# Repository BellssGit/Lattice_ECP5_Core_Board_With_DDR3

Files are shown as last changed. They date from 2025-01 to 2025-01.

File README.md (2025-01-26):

# Lattice_ECP5_Core_Board_With_DDR3
A 6 layer Board, Using Lattice LFE5U-25F-BGA256 FPGA with 32bit wide DDR3 memory.

board

Connectivity:
  
  1. 8 Channel LVDS working up to 800Mbps per channel
  2. 24bit RGB display or general IO
  3. FT232H with FT245 FIFO support

On Board memory:
  
  1. 128Mbit Flash
  2. 2x2Gbit 16x2bit wide DDR3 memory

A [blog post](https://www.emoe.xyz/lattice_ecp5_board/) about this board (Chinese Only)

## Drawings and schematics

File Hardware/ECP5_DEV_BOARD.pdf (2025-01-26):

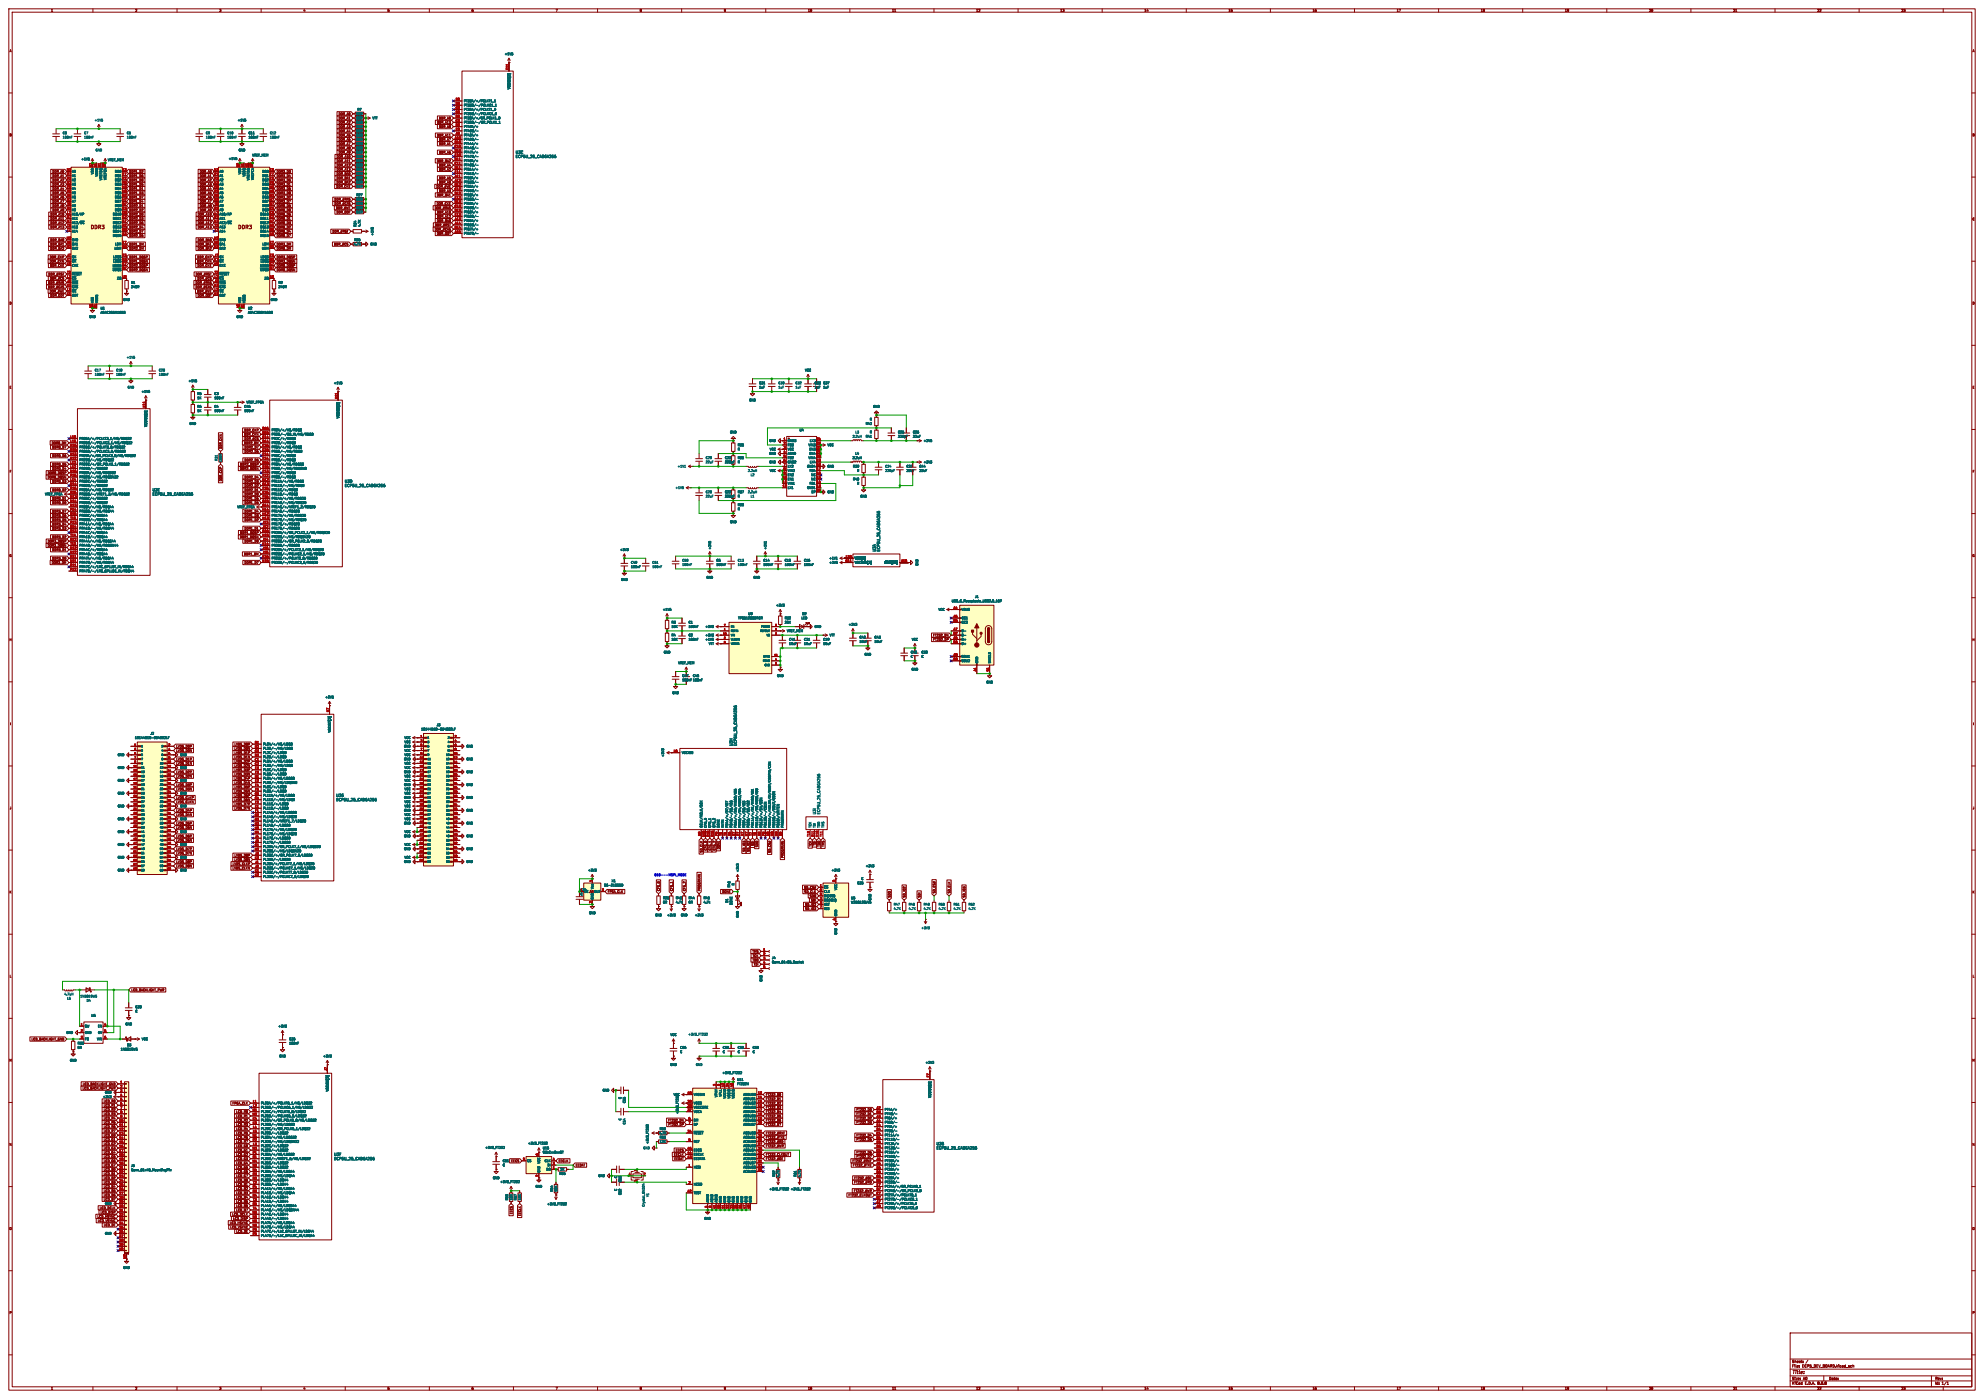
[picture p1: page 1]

DDR_A12 DDR_A11 DDR_A13 DDR_A10 DDR_A9 DDR_A8 DDR_#RST DDR_#RAS DDR_#CAS DDR_#CS DDR_#WE DDR_ODT DDR_BA2 DDR_BA1 DDR_BA0 DDR_CKP DDR_CKE DDR_CKN

GND GND GND GND GND GND GND GND GND

VCC GND GND GND
VCC

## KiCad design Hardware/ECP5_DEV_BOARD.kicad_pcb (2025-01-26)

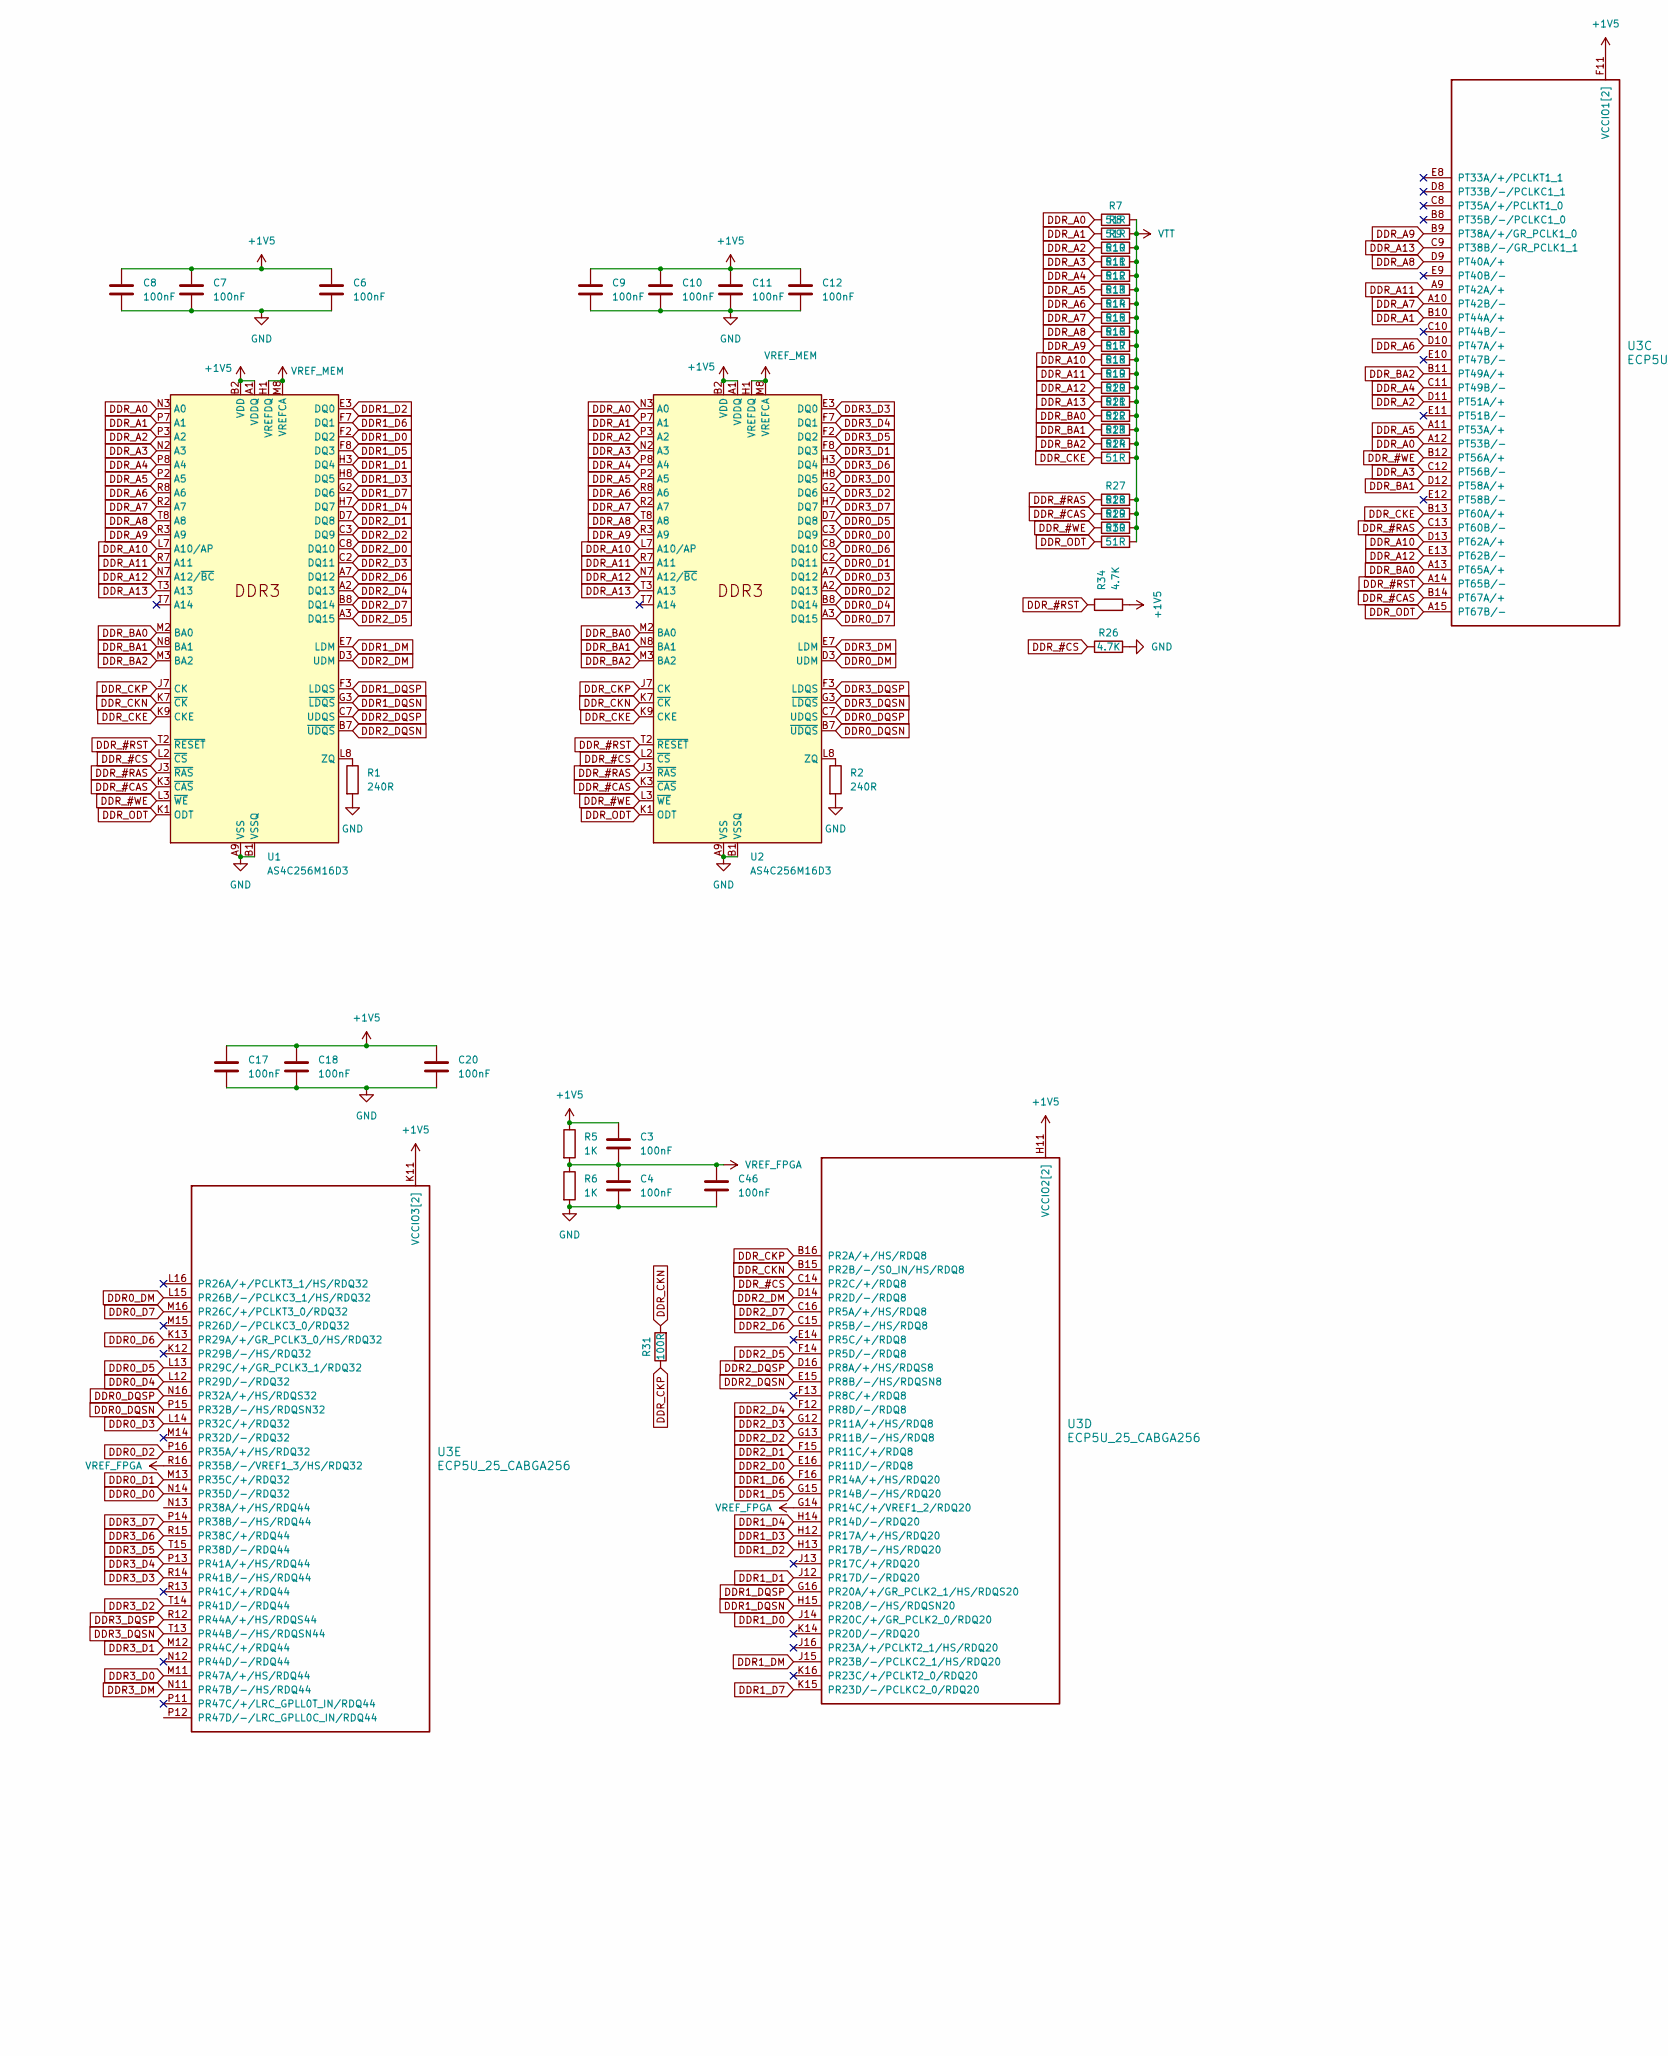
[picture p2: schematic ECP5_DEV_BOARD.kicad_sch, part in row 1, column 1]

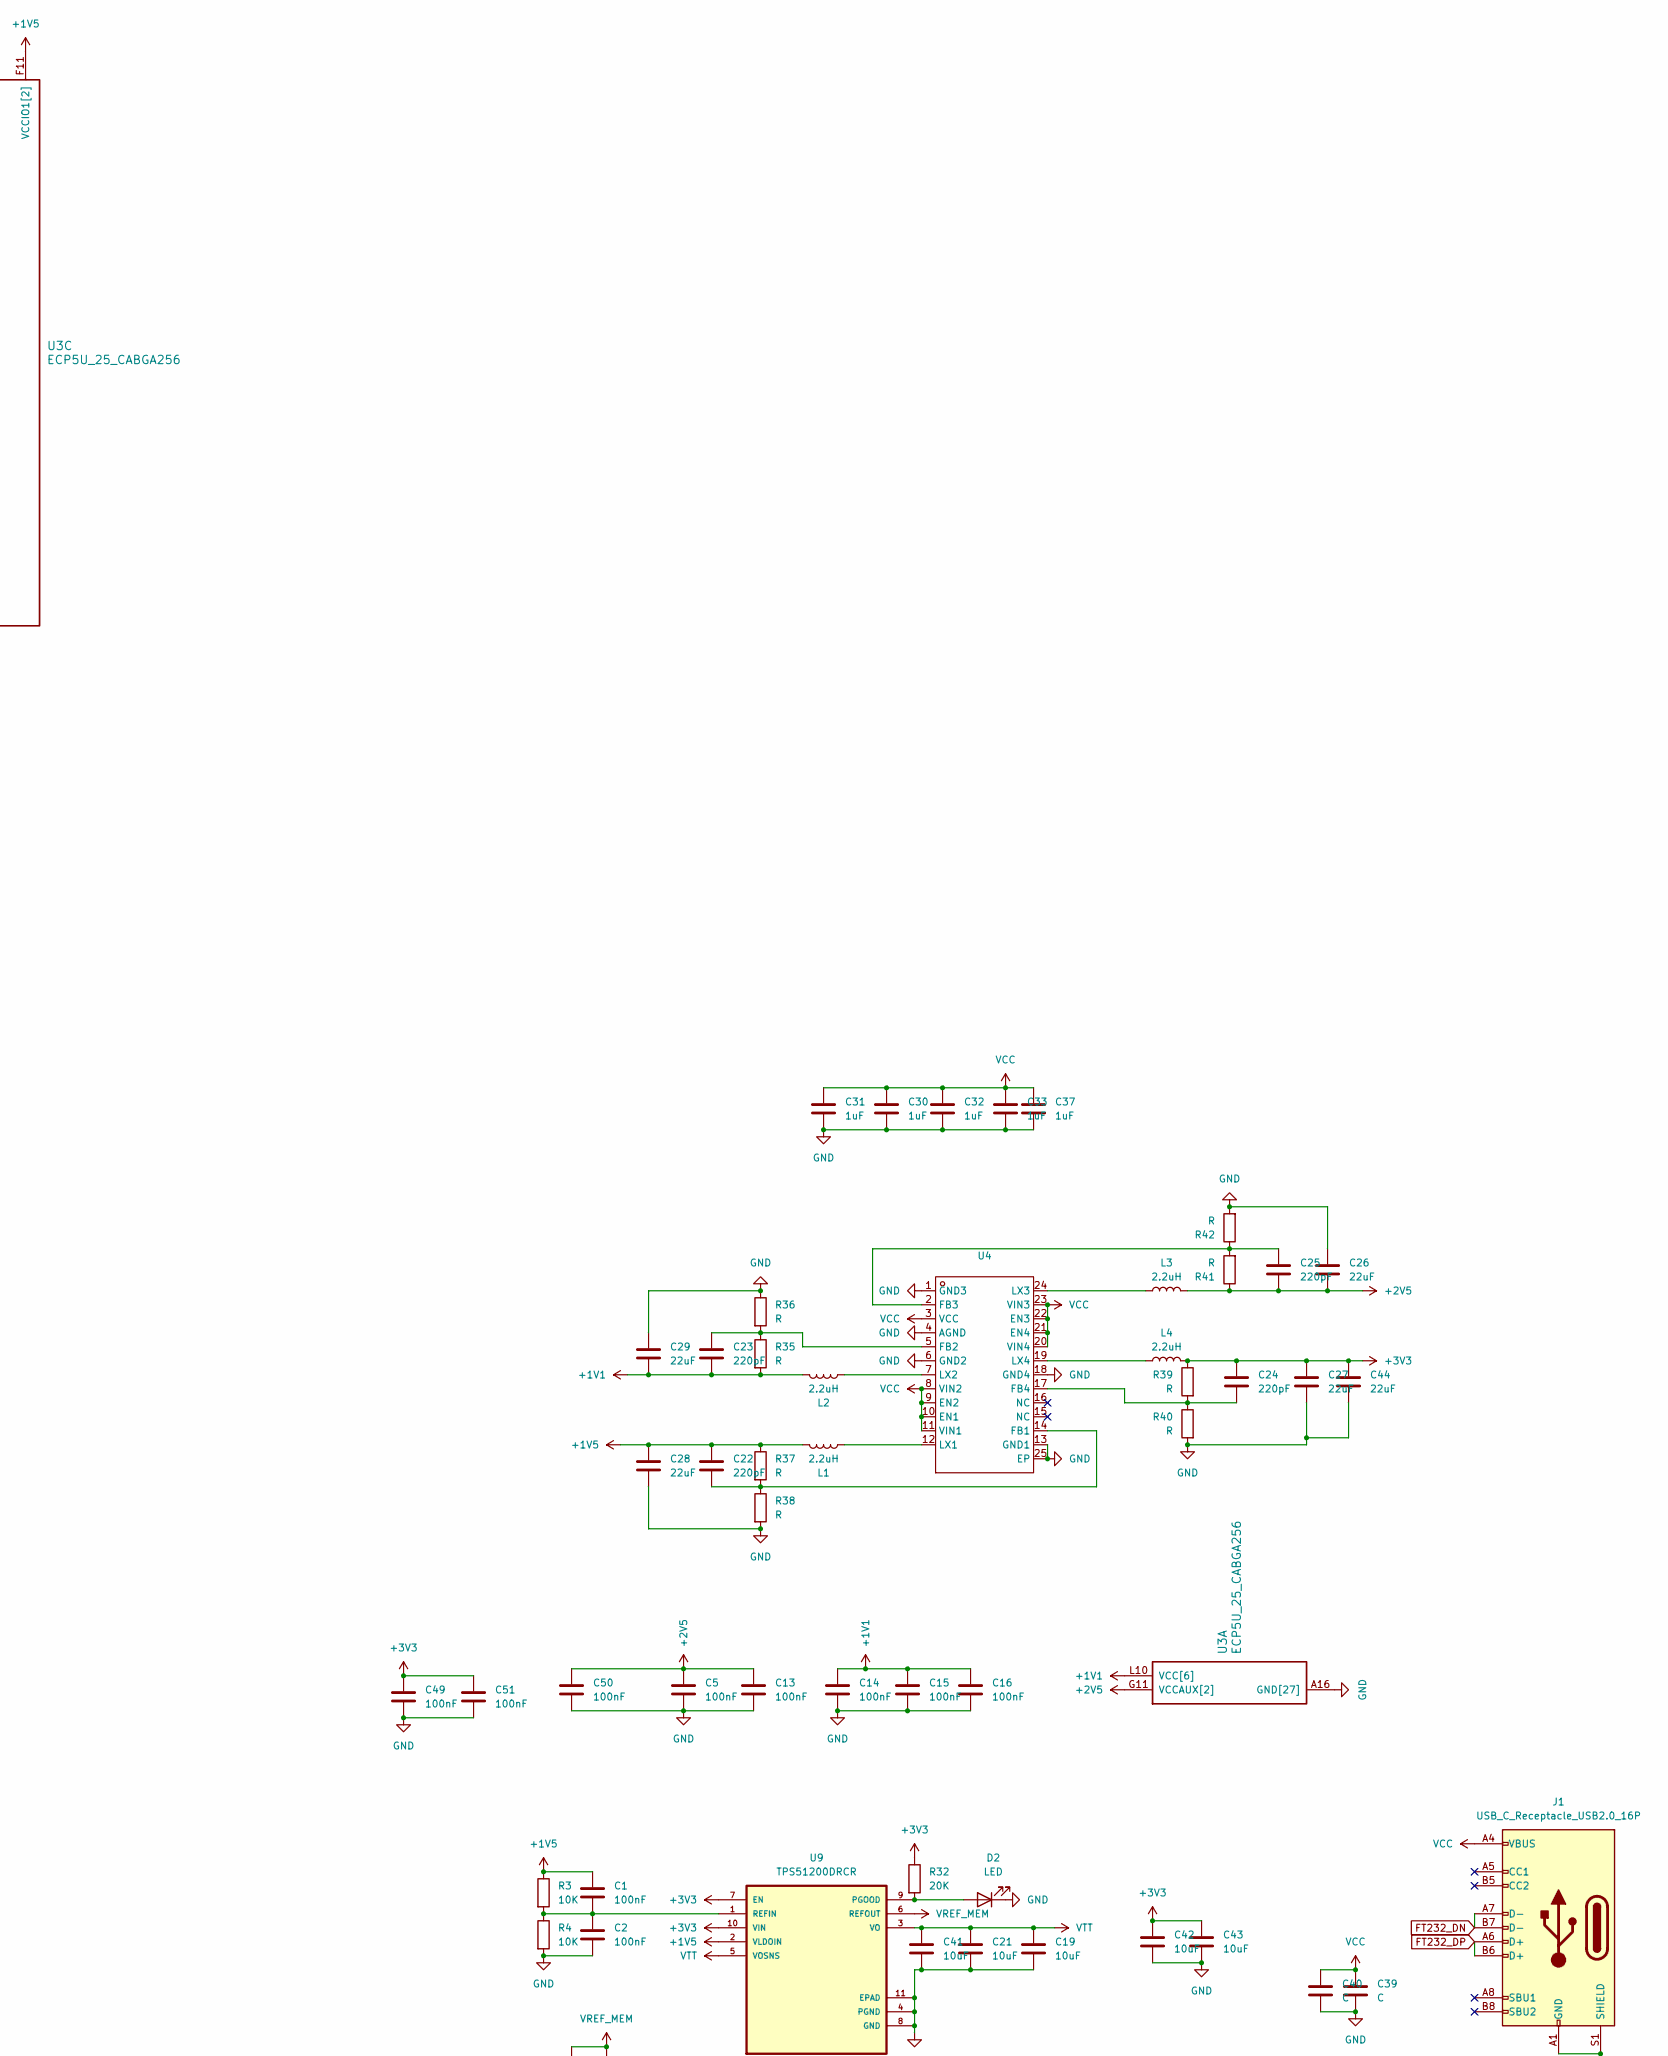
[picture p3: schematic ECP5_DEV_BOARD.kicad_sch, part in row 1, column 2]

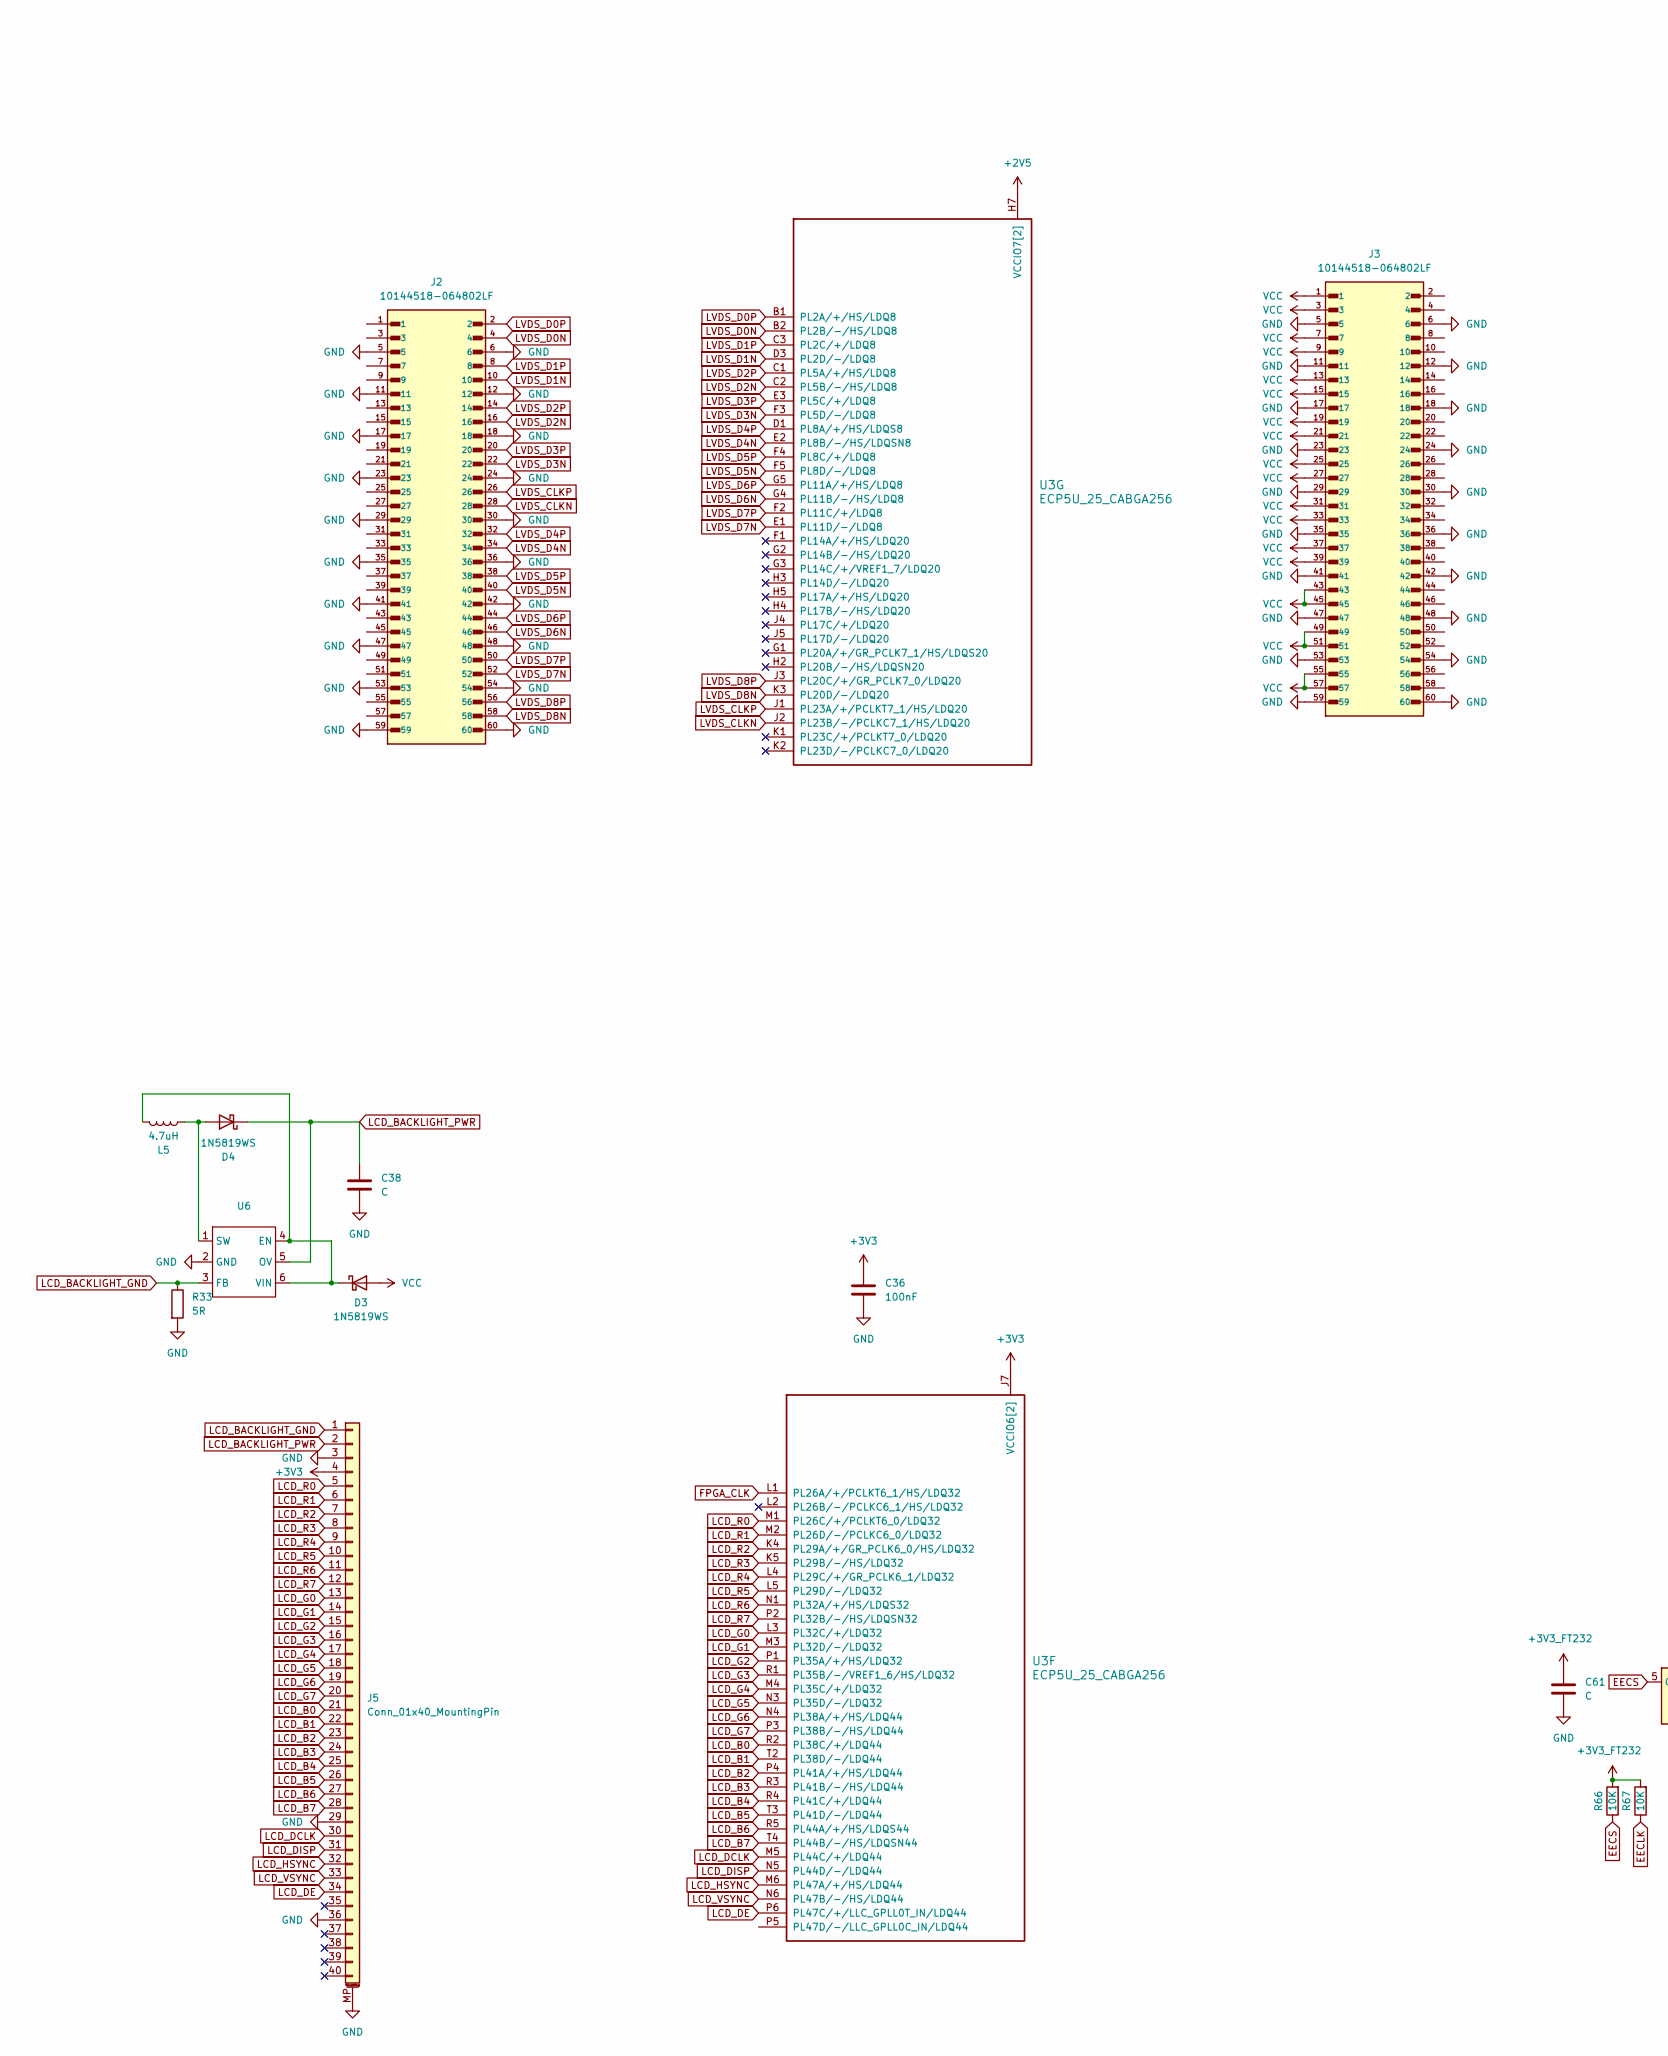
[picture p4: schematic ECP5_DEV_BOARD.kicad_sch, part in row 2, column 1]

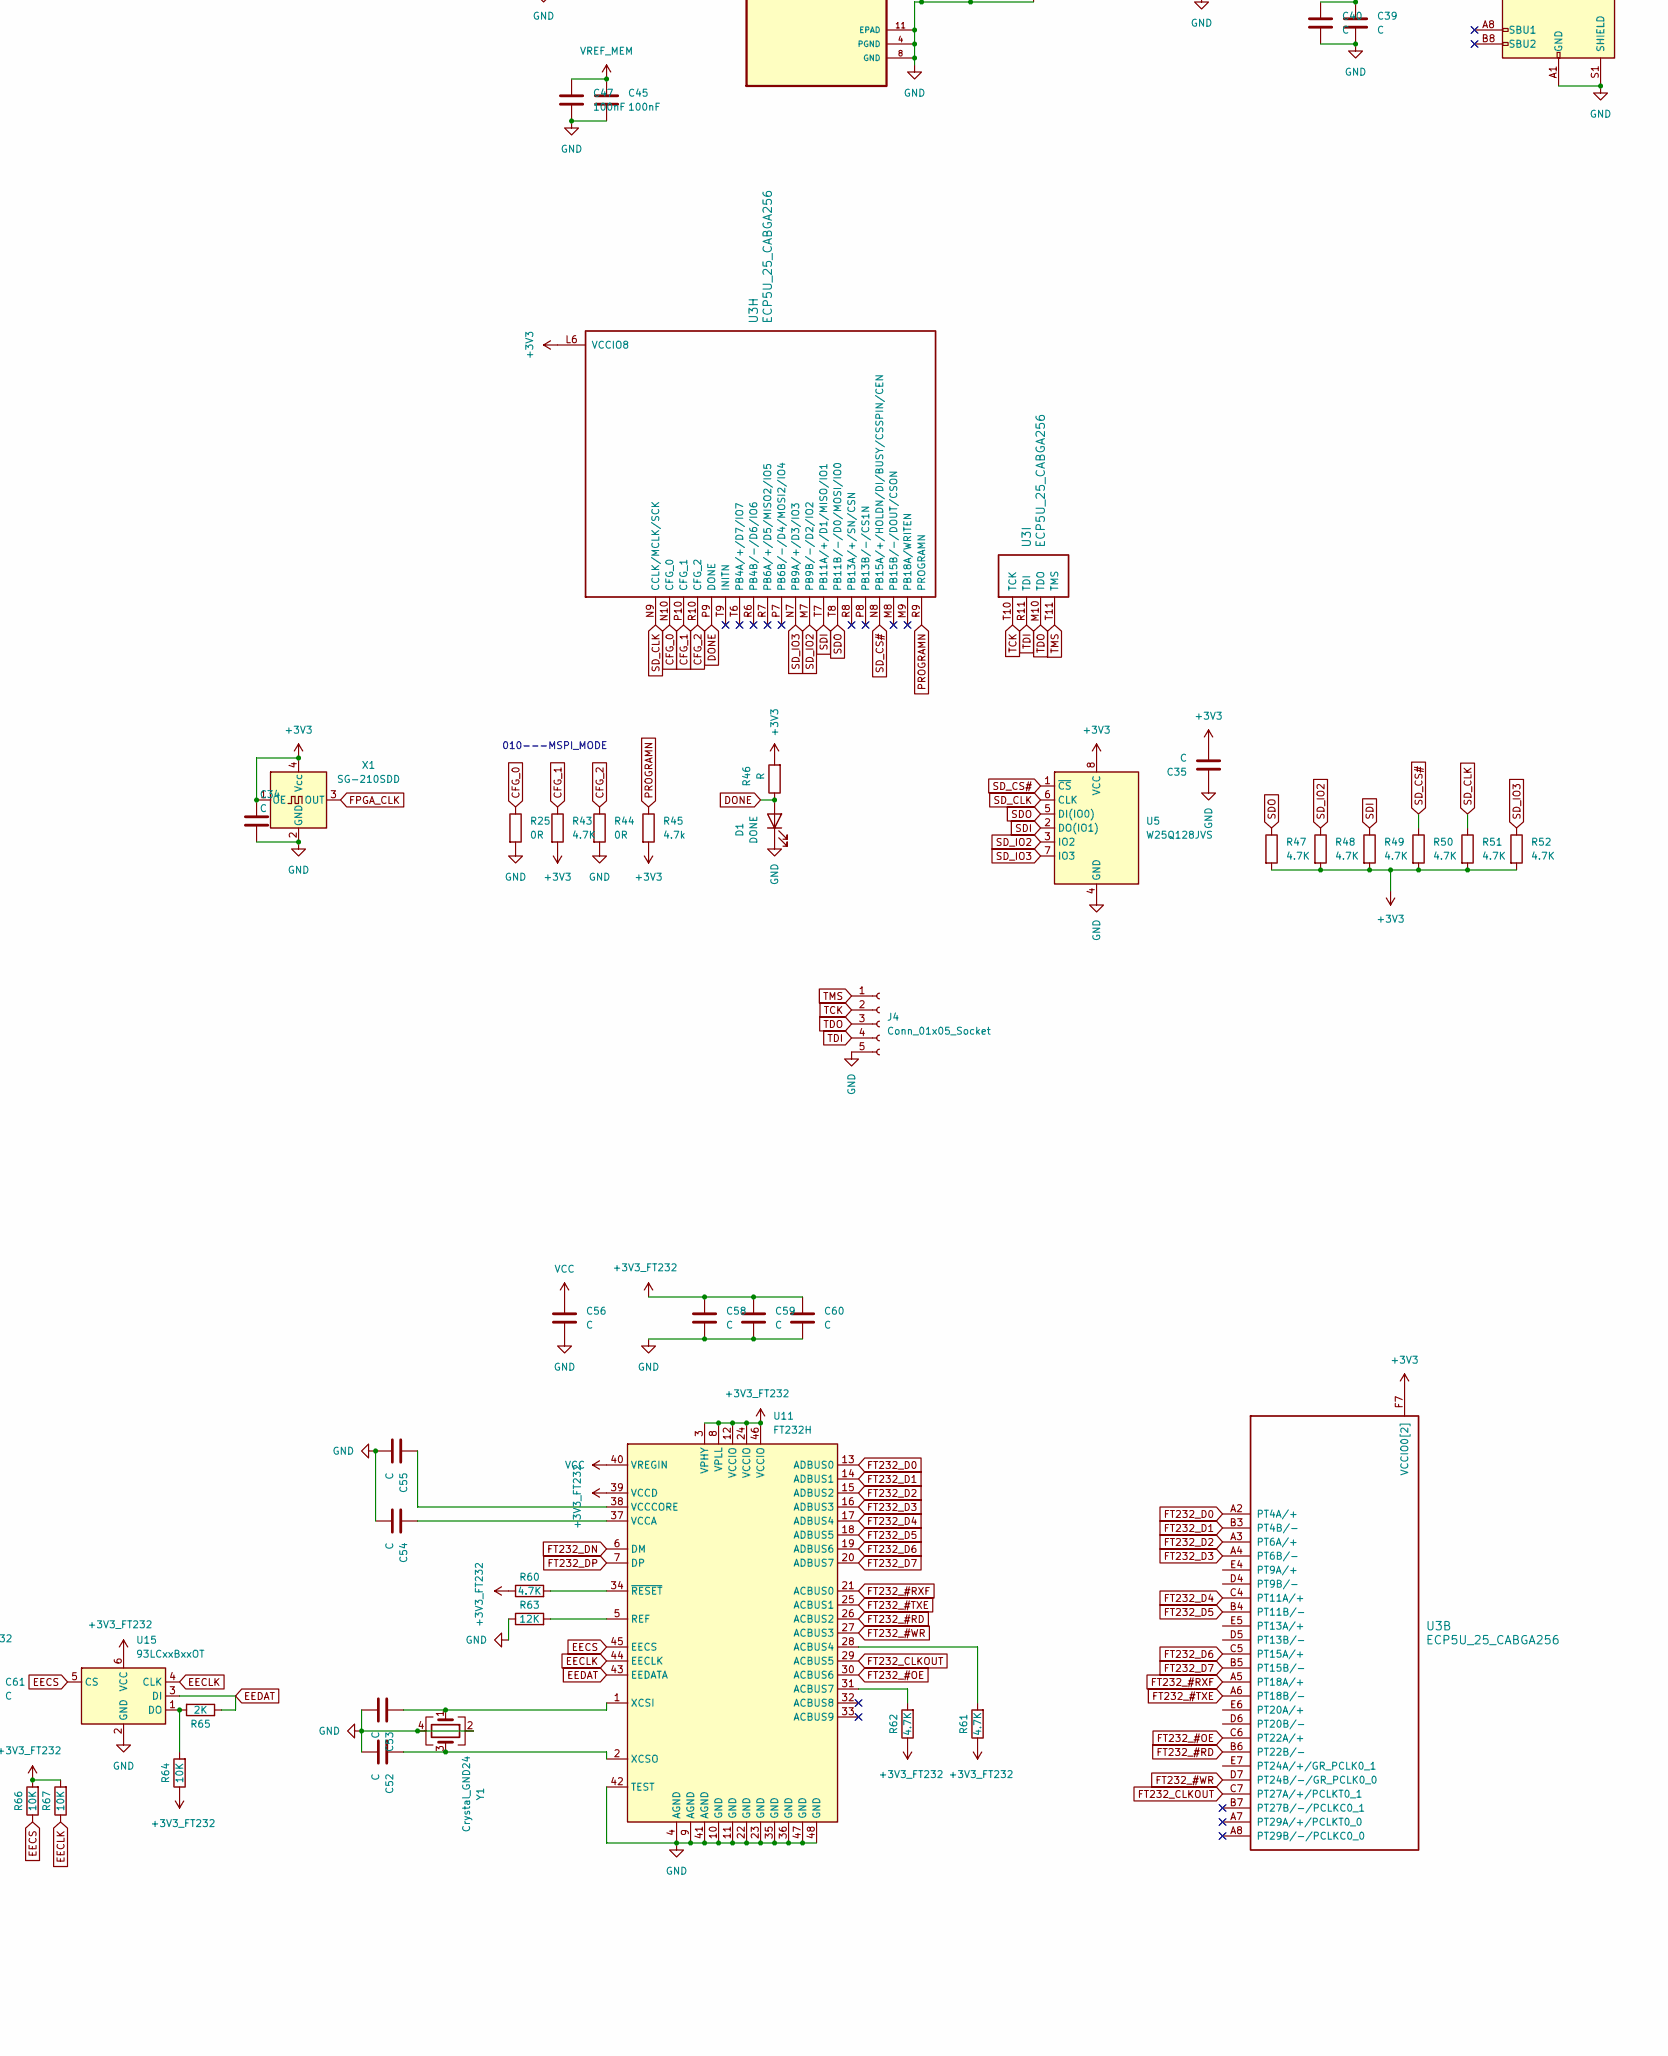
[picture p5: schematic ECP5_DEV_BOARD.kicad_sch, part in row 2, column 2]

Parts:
C1, C2, C3, C4, C47: 100nF; C_0603_1608Metric
C5, C6, C7, C8, C9, C10, C11, C12, C13, C14, C15, C16, C17, C18, C20, C36, C45, C46, C49, C50, C51: 100nF; C_0402_1005Metric
C19, C21, C41, C42, C43: 10uF; C_0603_1608Metric
C22, C23, C24, C25: 220pF; C_0603_1608Metric
C26, C27, C28, C29, C44: 22uF; C_0805_2012Metric
C30, C31, C32, C33, C37: 1uF; C_0603_1608Metric
C34, C35, C52, C53, C54, C55, C56, C58, C59, C60, C61: C; C_0603_1608Metric
C38, C39, C40: C; C_0805_2012Metric
D1: DONE; LED_0603_1608Metric_Pad1.05x0.95mm_HandSolder
D2: LED; LED_0603_1608Metric
D3, D4: 1N5819WS; D_SOD-323
J1: USB_C_Receptacle_USB2.0_16P; USB_C_Receptacle_G-Switch_GT-USB-7010ASV
J2, J3: 10144518-064802LF; AMPHENOL_10144518-064802LF; PARTREV H
J4: Conn_01x05_Socket; PinSocket_1x05_P2.54mm_Vertical
J5: Conn_01x40_MountingPin; TE_4-1734839-0_1x40-1MP_P0.5mm_Horizontal
L1, L2, L3, L4: 2.2uH; L_Changjiang_FNR252010S
L5: 4.7uH; L_Changjiang_FNR252010S
R1, R2: 240R; R_0402_1005Metric
R3, R4, R64, R66, R67: 10K; R_0603_1608Metric
R5, R6: 1K; R_0603_1608Metric
R7, R8, R9, R10, R11, R12, R13, R14, R15, R16, R17, R18, R19, R20, R21, R22, R23, R24, R27, R28, R29, R30: 51R; R_0402_1005Metric
R25, R44: 0R; R_0402_1005Metric
R26, R34, R43: 4.7K; R_0402_1005Metric
R31: 100R; R_0402_1005Metric
R32: 20K; R_0603_1608Metric
R33: 5R; R_0603_1608Metric
R35, R36, R37, R38, R39, R40, R41, R42: R; R_0603_1608Metric
R45: 4.7k; R_0402_1005Metric
R46: R; R_0603_1608Metric_Pad0.98x0.95mm_HandSolder
R47, R48, R49, R50, R51, R52: 4.7K; R_0603_1608Metric_Pad0.98x0.95mm_HandSolder
R60, R61, R62: 4.7K; R_0603_1608Metric
R63: 12K; R_0603_1608Metric
R65: 2K; R_0603_1608Metric
U1, U2: AS4C256M16D3; BGA-96_9.0x13.0mm_Layout2x3x16_P0.8mm
U3: ECP5U_25_CABGA256; BGA-256_14.0x14.0mm_Layout16x16_P0.8mm_Ball0.45mm_Pad0.32mm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
U4: VQFN-24-1EP_4x4mm_P0.5mm_EP2.5x2.5mm
U5: W25Q128JVS; SOIC-8_5.23x5.23mm_P1.27mm
U6: SOT-23-6
U9: TPS51200DRCR; VREG_V62_16624-01YE
U11: FT232H; LQFP-48_7x7mm_P0.5mm
U15: 93LCxxBxxOT; SOT-23-6
X1: SG-210SDD; Oscillator_SMD_Abracon_ASE-4Pin_3.2x2.5mm
Y1: Crystal_GND24; Crystal_SMD_3225-4Pin_3.2x2.5mm

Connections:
+1V1: C14.1, C15.1, C16.1, C23.2, C29.2, L2.1, R35.2, U3.G6 (VCC[6]), U3.G7 (VCC[6]), U3.G9 (VCC[6]), U3.L8 (VCC[6]), U3.L9 (VCC[6]), U3.L10 (VCC[6])
+1V5: C1.1, C3.1, C6.1, C7.1, C8.1, C9.1, C10.1, C11.1, C12.1, C17.1, C18.1, C20.1, C22.1, C28.1, L1.1, R3.1, R5.1, R34.2, R37.1, U1.A1 (VDDQ), U1.A8 (VDDQ), U1.B2 (VDD), U1.C1 (VDDQ), U1.C9 (VDDQ), U1.D2 (VDDQ), U1.D9 (VDD), U1.E9 (VDDQ), U1.F1 (VDDQ), U1.G7 (VDD), U1.H2 (VDDQ), U1.H9 (VDDQ), U1.K2 (VDD), U1.K8 (VDD), U1.N1 (VDD), U1.N9 (VDD), U1.R1 (VDD), U1.R9 (VDD), U2.A1 (VDDQ), U2.A8 (VDDQ), U2.B2 (VDD), U2.C1 (VDDQ), U2.C9 (VDDQ), U2.D2 (VDDQ), U2.D9 (VDD), U2.E9 (VDDQ), U2.F1 (VDDQ), U2.G7 (VDD), U2.H2 (VDDQ), U2.H9 (VDDQ), U2.K2 (VDD), U2.K8 (VDD), U2.N1 (VDD), U2.N9 (VDD), U2.R1 (VDD), U2.R9 (VDD), U3.F10 (VCCIO1[2]), U3.F11 (VCCIO1[2]), U3.H11 (VCCIO2[2]), U3.J11 (VCCIO2[2]), U3.K11 (VCCIO3[2]), U3.L11 (VCCIO3[2]), U9.2 (VLDOIN)
+2V5: C5.1, C13.1, C25.1, C26.2, C50.1, L3.2, R41.1, U3.G11 (VCCAUX[2]), U3.H6 (VCCIO7[2]), U3.H7 (VCCIO7[2]), U3.L7 (VCCAUX[2])
+3V3: C24.1, C27.1, C34.1, C35.2, C36.1, C42.1, C43.1, C44.1, C49.1, C51.1, J5.4, L4.2, R32.1, R39.1, R43.2, R45.2, R46.2, R47.2, R48.2, R49.2, R50.2, R51.2, R52.2, U3.F6 (VCCIO0[2]), U3.F7 (VCCIO0[2]), U3.J6 (VCCIO6[2]), U3.J7 (VCCIO6[2]), U3.L6 (VCCIO8), U5.8 (VCC), U9.7 (EN), U9.10 (VIN), X1.1 (OE), X1.4 (Vcc)
+3V3_FT232: C58.1, C59.1, C60.1, C61.1, R60.1, R61.1, R62.1, R64.1, R66.2, R67.2, U11.3 (VPHY), U11.8 (VPLL), U11.12 (VCCIO), U11.24 (VCCIO), U11.39 (VCCD), U11.46 (VCCIO), U15.6 (VCC)
CFG_0: R25.1, U3.N10 (CFG_0)
CFG_1: R43.1, U3.P10 (CFG_1)
CFG_2: R44.1, U3.R10 (CFG_2)
DDR0_D0: U2.C3 (DQ9), U3.N14 (PR35D/-/RDQ32)
DDR0_D1: U2.C2 (DQ11), U3.M13 (PR35C/+/RDQ32)
DDR0_D2: U2.A2 (DQ13), U3.P16 (PR35A/+/HS/RDQ32)
DDR0_D3: U2.A7 (DQ12), U3.L14 (PR32C/+/RDQ32)
DDR0_D4: U2.B8 (DQ14), U3.L12 (PR29D/-/RDQ32)
DDR0_D5: U2.D7 (DQ8), U3.L13 (PR29C/+/GR_PCLK3_1/RDQ32)
DDR0_D6: U2.C8 (DQ10), U3.K13 (PR29A/+/GR_PCLK3_0/HS/RDQ32)
DDR0_D7: U2.A3 (DQ15), U3.M16 (PR26C/+/PCLKT3_0/RDQ32)
DDR0_DM: U2.D3 (UDM), U3.L15 (PR26B/-/PCLKC3_1/HS/RDQ32)
DDR0_DQSN: U2.B7 (~UDQS), U3.P15 (PR32B/-/HS/RDQSN32)
DDR0_DQSP: U2.C7 (UDQS), U3.N16 (PR32A/+/HS/RDQS32)
DDR1_D0: U1.F2 (DQ2), U3.J14 (PR20C/+/GR_PCLK2_0/RDQ20)
DDR1_D1: U1.H3 (DQ4), U3.J12 (PR17D/-/RDQ20)
DDR1_D2: U1.E3 (DQ0), U3.H13 (PR17B/-/HS/RDQ20)
DDR1_D3: U1.H8 (DQ5), U3.H12 (PR17A/+/HS/RDQ20)
DDR1_D4: U1.H7 (DQ7), U3.H14 (PR14D/-/RDQ20)
DDR1_D5: U1.F8 (DQ3), U3.G15 (PR14B/-/HS/RDQ20)
DDR1_D6: U1.F7 (DQ1), U3.F16 (PR14A/+/HS/RDQ20)
DDR1_D7: U1.G2 (DQ6), U3.K15 (PR23D/-/PCLKC2_0/RDQ20)
DDR1_DM: U1.E7 (LDM), U3.J15 (PR23B/-/PCLKC2_1/HS/RDQ20)
DDR1_DQSN: U1.G3 (~LDQS), U3.H15 (PR20B/-/HS/RDQSN20)
DDR1_DQSP: U1.F3 (LDQS), U3.G16 (PR20A/+/GR_PCLK2_1/HS/RDQS20)
DDR2_D0: U1.C8 (DQ10), U3.E16 (PR11D/-/RDQ8)
DDR2_D1: U1.D7 (DQ8), U3.F15 (PR11C/+/RDQ8)
DDR2_D2: U1.C3 (DQ9), U3.G13 (PR11B/-/HS/RDQ8)
DDR2_D3: U1.C2 (DQ11), U3.G12 (PR11A/+/HS/RDQ8)
DDR2_D4: U1.A2 (DQ13), U3.F12 (PR8D/-/RDQ8)
DDR2_D5: U1.A3 (DQ15), U3.F14 (PR5D/-/RDQ8)
DDR2_D6: U1.A7 (DQ12), U3.C15 (PR5B/-/HS/RDQ8)
DDR2_D7: U1.B8 (DQ14), U3.C16 (PR5A/+/HS/RDQ8)
DDR2_DM: U1.D3 (UDM), U3.D14 (PR2D/-/RDQ8)
DDR2_DQSN: U1.B7 (~UDQS), U3.E15 (PR8B/-/HS/RDQSN8)
DDR2_DQSP: U1.C7 (UDQS), U3.D16 (PR8A/+/HS/RDQS8)
DDR3_D0: U2.H8 (DQ5), U3.M11 (PR47A/+/HS/RDQ44)
DDR3_D1: U2.F8 (DQ3), U3.M12 (PR44C/+/RDQ44)
DDR3_D2: U2.G2 (DQ6), U3.T14 (PR41D/-/RDQ44)
DDR3_D3: U2.E3 (DQ0), U3.R14 (PR41B/-/HS/RDQ44)
DDR3_D4: U2.F7 (DQ1), U3.P13 (PR41A/+/HS/RDQ44)
DDR3_D5: U2.F2 (DQ2), U3.T15 (PR38D/-/RDQ44)
DDR3_D6: U2.H3 (DQ4), U3.R15 (PR38C/+/RDQ44)
DDR3_D7: U2.H7 (DQ7), U3.P14 (PR38B/-/HS/RDQ44)
DDR3_DM: U2.E7 (LDM), U3.N11 (PR47B/-/HS/RDQ44)
DDR3_DQSN: U2.G3 (~LDQS), U3.T13 (PR44B/-/HS/RDQSN44)
DDR3_DQSP: U2.F3 (LDQS), U3.R12 (PR44A/+/HS/RDQS44)
DDR_#CAS: R28.1, U1.K3 (~CAS), U2.K3 (~CAS), U3.B14 (PT67A/+)
DDR_#CS: R26.1, U1.L2 (~CS), U2.L2 (~CS), U3.C14 (PR2C/+/RDQ8)
DDR_#RAS: R27.1, U1.J3 (~RAS), U2.J3 (~RAS), U3.C13 (PT60B/-)
DDR_#RST: R34.1, U1.T2 (~RESET), U2.T2 (~RESET), U3.A14 (PT65B/-)
DDR_#WE: R29.1, U1.L3 (~WE), U2.L3 (~WE), U3.B12 (PT56A/+)
DDR_A0: R7.1, U1.N3 (A0), U2.N3 (A0), U3.A12 (PT53B/-)
DDR_A1: R8.1, U1.P7 (A1), U2.P7 (A1), U3.B10 (PT44A/+)
DDR_A2: R9.1, U1.P3 (A2), U2.P3 (A2), U3.D11 (PT51A/+)
DDR_A3: R10.1, U1.N2 (A3), U2.N2 (A3), U3.C12 (PT56B/-)
DDR_A4: R11.1, U1.P8 (A4), U2.P8 (A4), U3.C11 (PT49B/-)
DDR_A5: R12.1, U1.P2 (A5), U2.P2 (A5), U3.A11 (PT53A/+)
DDR_A6: R13.1, U1.R8 (A6), U2.R8 (A6), U3.D10 (PT47A/+)
DDR_A7: R14.1, U1.R2 (A7), U2.R2 (A7), U3.A10 (PT42B/-)
DDR_A8: R15.1, U1.T8 (A8), U2.T8 (A8), U3.D9 (PT40A/+)
DDR_A9: R16.1, U1.R3 (A9), U2.R3 (A9), U3.B9 (PT38A/+/GR_PCLK1_0)
DDR_A10: R17.1, U1.L7 (A10/AP), U2.L7 (A10/AP), U3.D13 (PT62A/+)
DDR_A11: R18.1, U1.R7 (A11), U2.R7 (A11), U3.A9 (PT42A/+)
DDR_A12: R19.1, U1.N7 (A12/~BC), U2.N7 (A12/~BC), U3.E13 (PT62B/-)
DDR_A13: R20.1, U1.T3 (A13), U2.T3 (A13), U3.C9 (PT38B/-/GR_PCLK1_1)
DDR_BA0: R21.1, U1.M2 (BA0), U2.M2 (BA0), U3.A13 (PT65A/+)
DDR_BA1: R22.1, U1.N8 (BA1), U2.N8 (BA1), U3.D12 (PT58A/+)
DDR_BA2: R23.1, U1.M3 (BA2), U2.M3 (BA2), U3.B11 (PT49A/+)
DDR_CKE: R24.1, U1.K9 (CKE), U2.K9 (CKE), U3.B13 (PT60A/+)
DDR_CKN: R31.2, U1.K7 (~CK), U2.K7 (~CK), U3.B15 (PR2B/-/S0_IN/HS/RDQ8)
DDR_CKP: R31.1, U1.J7 (CK), U2.J7 (CK), U3.B16 (PR2A/+/HS/RDQ8)
DDR_ODT: R30.1, U1.K1 (ODT), U2.K1 (ODT), U3.A15 (PT67B/-)
DONE: D1.2 (A), R46.1, U3.P9 (DONE)
EECLK: R67.1, U11.44 (EECLK), U15.4 (CLK)
EECS: R66.1, U11.45 (EECS), U15.5 (CS)
EEDAT: R65.1, U11.43 (EEDATA), U15.3 (DI)
FPGA_CLK: U3.L1 (PL26A/+/PCLKT6_1/HS/LDQ32), X1.3 (OUT)
FT232_#OE: U3.C6 (PT22A/+), U11.30 (ACBUS6)
FT232_#RD: U3.B6 (PT22B/-), U11.26 (ACBUS2)
FT232_#RXF: U3.A5 (PT18A/+), U11.21 (ACBUS0)
FT232_#TXE: U3.A6 (PT18B/-), U11.25 (ACBUS1)
FT232_#WR: U3.D7 (PT24B/-/GR_PCLK0_0), U11.27 (ACBUS3)
FT232_CLKOUT: U3.C7 (PT27A/+/PCLKT0_1), U11.29 (ACBUS5)
FT232_D0: U3.A2 (PT4A/+), U11.13 (ADBUS0)
FT232_D1: U3.B3 (PT4B/-), U11.14 (ADBUS1)
FT232_D2: U3.A3 (PT6A/+), U11.15 (ADBUS2)
FT232_D3: U3.A4 (PT6B/-), U11.16 (ADBUS3)
FT232_D4: U3.C4 (PT11A/+), U11.17 (ADBUS4)
FT232_D5: U3.B4 (PT11B/-), U11.18 (ADBUS5)
FT232_D6: U3.C5 (PT15A/+), U11.19 (ADBUS6)
FT232_D7: U3.B5 (PT15B/-), U11.20 (ADBUS7)
FT232_DN: J1.A7 (D-), J1.B7 (D-), U11.6 (DM)
FT232_DP: J1.A6 (D+), J1.B6 (D+), U11.7 (DP)
GND: C2.2, C4.2, C5.2, C6.2, C7.2, C8.2, C9.2, C10.2, C11.2, C12.2, C13.2, C14.2, C15.2, C16.2, C17.2, C18.2, C19.2, C20.2, C21.2, C26.1, C27.2, C28.2, C29.1, C30.1, C31.1, C32.1, C33.1, C34.2, C35.1, C36.2, C37.1, C38.2, C39.2, C40.2, C41.2, C42.2, C43.2, C44.2, C45.2, C46.2, C47.2, C49.2, C50.2, C51.2, C52.2, C53.2, C54.2, C55.2, C56.2, C58.2, C59.2, C60.2, C61.2, D1.1 (K), D2.1 (K), J1.A1 (GND), J1.A12 (GND), J1.B1 (GND), J1.B12 (GND), J1.S1 (SHIELD), J2.5, J2.6, J2.11, J2.12, J2.17, J2.18, J2.23, J2.24, J2.29, J2.30, J2.35, J2.36, J2.41, J2.42, J2.47, J2.48, J2.53, J2.54, J2.59, J2.60, J3.5, J3.6, J3.11, J3.12, J3.17, J3.18, J3.23, J3.24, J3.29, J3.30, J3.35, J3.36, J3.41, J3.42, J3.47, J3.48, J3.53, J3.54, J3.59, J3.60, J4.5, J5.3, J5.29, J5.36, J5.MP (MountPin), R1.2, R2.2, R4.2, R6.2, R25.2, R26.2, R33.2, R36.1, R38.2, R40.2, R42.2, R44.2, R63.1, U1.A9 (VSS), U1.B1 (VSSQ), U1.B3 (VSS), U1.B9 (VSSQ), U1.D1 (VSSQ), U1.D8 (VSSQ), U1.E1 (VSS), U1.E2 (VSSQ), U1.E8 (VSSQ), U1.F9 (VSSQ), U1.G1 (VSSQ), U1.G8 (VSS), U1.G9 (VSSQ), U1.J2 (VSS), U1.J8 (VSS), U1.M1 (VSS), U1.M9 (VSS), U1.P1 (VSS), U1.P9 (VSS), U1.T1 (VSS), U1.T9 (VSS), U2.A9 (VSS), U2.B1 (VSSQ), U2.B3 (VSS), U2.B9 (VSSQ), U2.D1 (VSSQ), U2.D8 (VSSQ), U2.E1 (VSS), U2.E2 (VSSQ), U2.E8 (VSSQ), U2.F9 (VSSQ), U2.G1 (VSSQ), U2.G8 (VSS), U2.G9 (VSSQ), U2.J2 (VSS), U2.J8 (VSS), U2.M1 (VSS), U2.M9 (VSS), U2.P1 (VSS), U2.P9 (VSS), U2.T1 (VSS), U2.T9 (VSS), U3.A1 (GND[27]), U3.A16 (GND[27]), U3.D2 (GND[27]), U3.D15 (GND[27]), U3.F8 (GND[27]), U3.F9 (GND[27]), U3.G8 (GND[27]), U3.G10 (GND[27]), U3.H1 (GND[27]), U3.H8 (GND[27]), U3.H9 (GND[27]), U3.H10 (GND[27]), U3.H16 (GND[27]), U3.J8 (GND[27]), U3.J9 (GND[27]), U3.J10 (GND[27]), U3.K6 (GND[27]), U3.K7 (GND[27]), U3.K8 (GND[27]), U3.K9 (GND[27]), U3.K10 (GND[27]), U3.N2 (GND[27]), U3.N15 (GND[27]), U3.T1 (GND[27]), U3.T5 (GND[27]), U3.T12 (GND[27]), U3.T16 (GND[27]), U4.1 (GND3), U4.4 (AGND), U4.6 (GND2), U4.13 (GND1), U4.18 (GND4), U4.25 (EP), U5.4 (GND), U6.2 (GND), U9.4 (PGND), U9.8 (GND), U9.11 (EPAD), U11.4 (AGND), U11.9 (AGND), U11.10 (GND), U11.11 (GND), U11.22 (GND), U11.23 (GND), U11.35 (GND), U11.36 (GND), U11.41 (AGND), U11.42 (TEST), U11.47 (GND), U11.48 (GND), U15.2 (GND), X1.2 (GND), Y1.2, Y1.4
LCD_B0: J5.21, U3.R2 (PL38C/+/LDQ44)
LCD_B1: J5.22, U3.T2 (PL38D/-/LDQ44)
LCD_B2: J5.23, U3.P4 (PL41A/+/HS/LDQ44)
LCD_B3: J5.24, U3.R3 (PL41B/-/HS/LDQ44)
LCD_B4: J5.25, U3.R4 (PL41C/+/LDQ44)
LCD_B5: J5.26, U3.T3 (PL41D/-/LDQ44)
LCD_B6: J5.27, U3.R5 (PL44A/+/HS/LDQS44)
LCD_B7: J5.28, U3.T4 (PL44B/-/HS/LDQSN44)
LCD_BACKLIGHT_GND: J5.1, R33.1, U6.3 (FB)
LCD_BACKLIGHT_PWR: C38.1, D4.1 (K), J5.2, U6.5 (OV)
LCD_DCLK: J5.30, U3.M5 (PL44C/+/LDQ44)
LCD_DE: J5.34, U3.P6 (PL47C/+/LLC_GPLL0T_IN/LDQ44)
LCD_DISP: J5.31, U3.N5 (PL44D/-/LDQ44)
LCD_G0: J5.13, U3.L3 (PL32C/+/LDQ32)
LCD_G1: J5.14, U3.M3 (PL32D/-/LDQ32)
LCD_G2: J5.15, U3.P1 (PL35A/+/HS/LDQ32)
LCD_G3: J5.16, U3.R1 (PL35B/-/VREF1_6/HS/LDQ32)
LCD_G4: J5.17, U3.M4 (PL35C/+/LDQ32)
LCD_G5: J5.18, U3.N3 (PL35D/-/LDQ32)
LCD_G6: J5.19, U3.N4 (PL38A/+/HS/LDQ44)
LCD_G7: J5.20, U3.P3 (PL38B/-/HS/LDQ44)
LCD_HSYNC: J5.32, U3.M6 (PL47A/+/HS/LDQ44)
LCD_R0: J5.5, U3.M1 (PL26C/+/PCLKT6_0/LDQ32)
LCD_R1: J5.6, U3.M2 (PL26D/-/PCLKC6_0/LDQ32)
LCD_R2: J5.7, U3.K4 (PL29A/+/GR_PCLK6_0/HS/LDQ32)
LCD_R3: J5.8, U3.K5 (PL29B/-/HS/LDQ32)
LCD_R4: J5.9, U3.L4 (PL29C/+/GR_PCLK6_1/LDQ32)
LCD_R5: J5.10, U3.L5 (PL29D/-/LDQ32)
LCD_R6: J5.11, U3.N1 (PL32A/+/HS/LDQS32)
LCD_R7: J5.12, U3.P2 (PL32B/-/HS/LDQSN32)
LCD_VSYNC: J5.33, U3.N6 (PL47B/-/HS/LDQ44)
LVDS_CLKN: J2.28, U3.J2 (PL23B/-/PCLKC7_1/HS/LDQ20)
LVDS_CLKP: J2.26, U3.J1 (PL23A/+/PCLKT7_1/HS/LDQ20)
LVDS_D0N: J2.4, U3.B2 (PL2B/-/HS/LDQ8)
LVDS_D0P: J2.2, U3.B1 (PL2A/+/HS/LDQ8)
LVDS_D1N: J2.10, U3.D3 (PL2D/-/LDQ8)
LVDS_D1P: J2.8, U3.C3 (PL2C/+/LDQ8)
LVDS_D2N: J2.16, U3.C2 (PL5B/-/HS/LDQ8)
LVDS_D2P: J2.14, U3.C1 (PL5A/+/HS/LDQ8)
LVDS_D3N: J2.22, U3.F3 (PL5D/-/LDQ8)
LVDS_D3P: J2.20, U3.E3 (PL5C/+/LDQ8)
LVDS_D4N: J2.34, U3.E2 (PL8B/-/HS/LDQSN8)
LVDS_D4P: J2.32, U3.D1 (PL8A/+/HS/LDQS8)
LVDS_D5N: J2.40, U3.F5 (PL8D/-/LDQ8)
LVDS_D5P: J2.38, U3.F4 (PL8C/+/LDQ8)
LVDS_D6N: J2.46, U3.G4 (PL11B/-/HS/LDQ8)
LVDS_D6P: J2.44, U3.G5 (PL11A/+/HS/LDQ8)
LVDS_D7N: J2.52, U3.E1 (PL11D/-/LDQ8)
LVDS_D7P: J2.50, U3.F2 (PL11C/+/LDQ8)
LVDS_D8N: J2.58, U3.K3 (PL20D/-/LDQ20)
LVDS_D8P: J2.56, U3.J3 (PL20C/+/GR_PCLK7_0/LDQ20)
unnamed: D2.2 (A), R32.2, U9.9 (PGOOD)
unnamed: D3.1 (K), L5.2, U6.4 (EN), U6.6 (VIN)
unnamed: D4.2 (A), L5.1, U6.1 (SW)
unnamed: R1.1, U1.L8 (ZQ)
unnamed: R2.1, U2.L8 (ZQ)
unnamed: C22.2, R37.2, R38.1, U4.14 (FB1)
unnamed: C23.1, R35.1, R36.2, U4.5 (FB2)
unnamed: C25.2, R41.2, R42.1, U4.2 (FB3)
unnamed: C24.2, R39.2, R40.1, U4.17 (FB4)
unnamed: L1.2, U4.12 (LX1)
unnamed: L2.2, U4.7 (LX2)
unnamed: L3.1, U4.24 (LX3)
unnamed: L4.1, U4.19 (LX4)
unnamed: C1.2, C2.1, R3.2, R4.1, U9.1 (REFIN)
unnamed: R61.2, U11.28 (ACBUS4)
unnamed: R62.2, U11.31 (ACBUS7)
unnamed: R63.2, U11.5 (REF)
unnamed: C54.1, U11.37 (VCCA)
unnamed: C55.1, U11.38 (VCCCORE)
unnamed: C53.1, U11.1 (XCSI), Y1.1
unnamed: C52.1, U11.2 (XCSO), Y1.3
unnamed: R60.2, U11.34 (~RESET)
unnamed: R64.2, R65.2, U15.1 (DO)
PROGRAMN: R45.1, U3.R9 (PROGRAMN)
SDI: R49.1, U3.T7 (PB11A/+/D1/MISO/IO1), U5.2 (DO(IO1))
SDO: R47.1, U3.T8 (PB11B/-/D0/MOSI/IO0), U5.5 (DI(IO0))
SD_CLK: R51.1, U3.N9 (CCLK/MCLK/SCK), U5.6 (CLK)
SD_CS#: R50.1, U3.N8 (PB15A/+/HOLDN/DI/BUSY/CSSPIN/CEN), U5.1 (~CS)
SD_IO2: R48.1, U3.M7 (PB9B/-/D2/IO2), U5.3 (IO2)
SD_IO3: R52.1, U3.N7 (PB9A/+/D3/IO3), U5.7 (IO3)
TCK: J4.2, U3.T10 (TCK)
TDI: J4.4, U3.R11 (TDI)
TDO: J4.3, U3.M10 (TDO)
TMS: J4.1, U3.T11 (TMS)
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

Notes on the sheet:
010---MSPI_MODE

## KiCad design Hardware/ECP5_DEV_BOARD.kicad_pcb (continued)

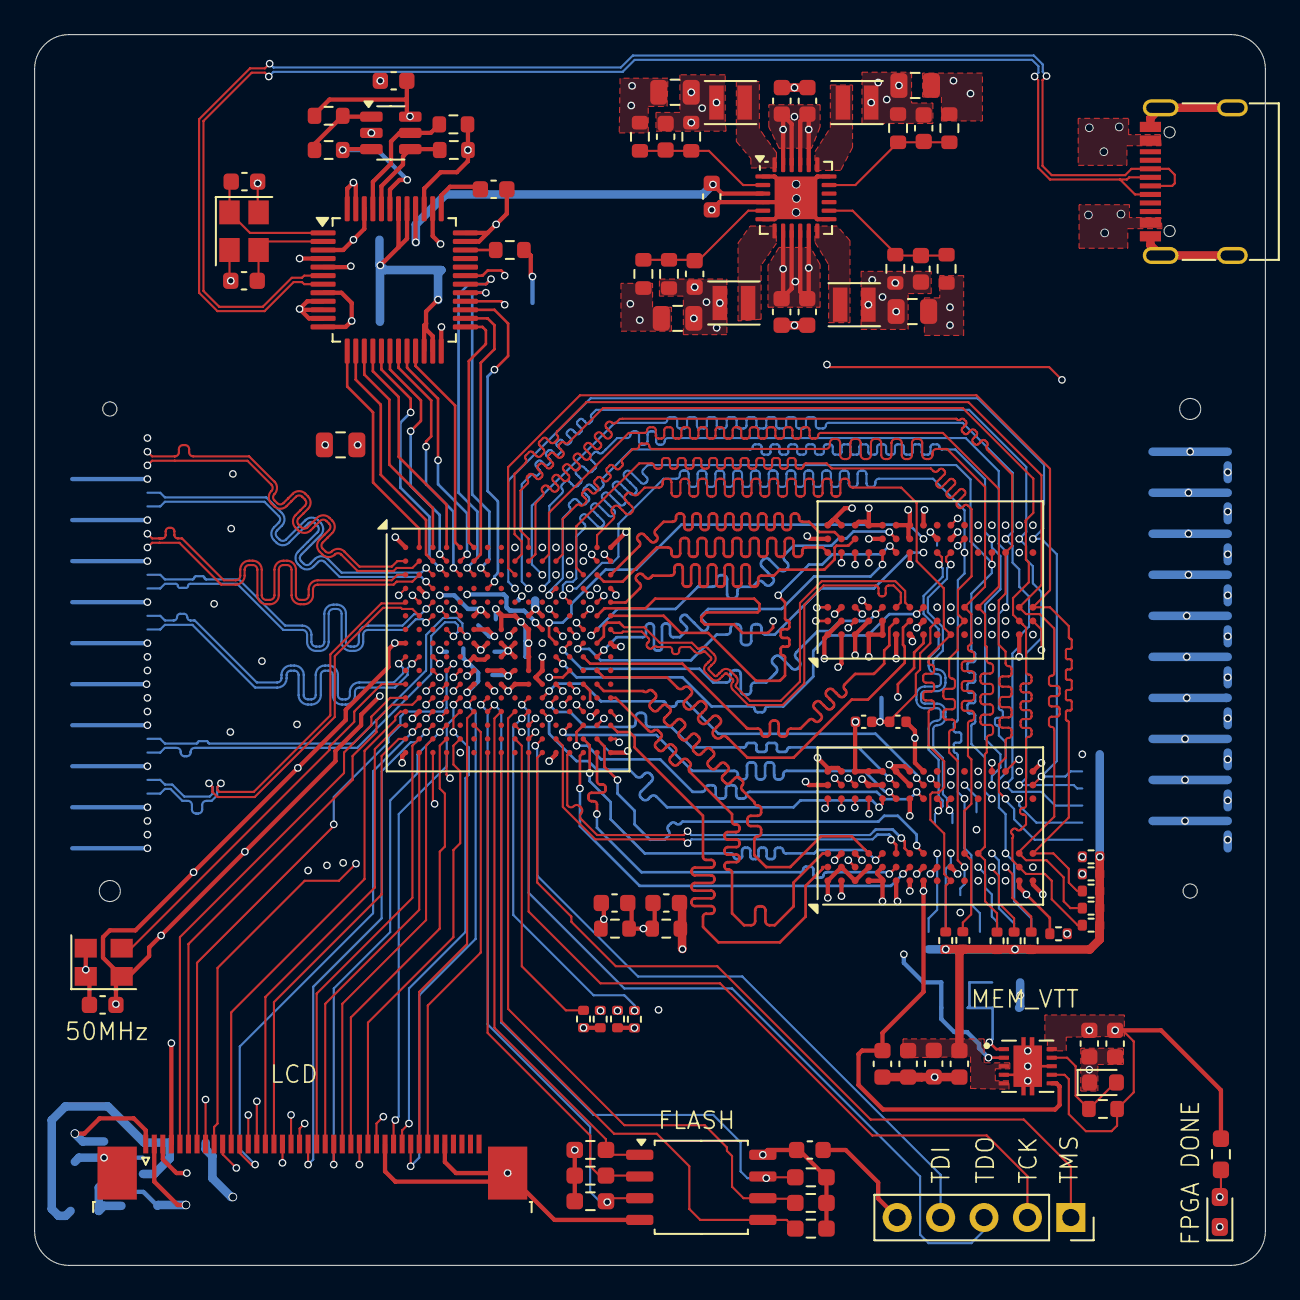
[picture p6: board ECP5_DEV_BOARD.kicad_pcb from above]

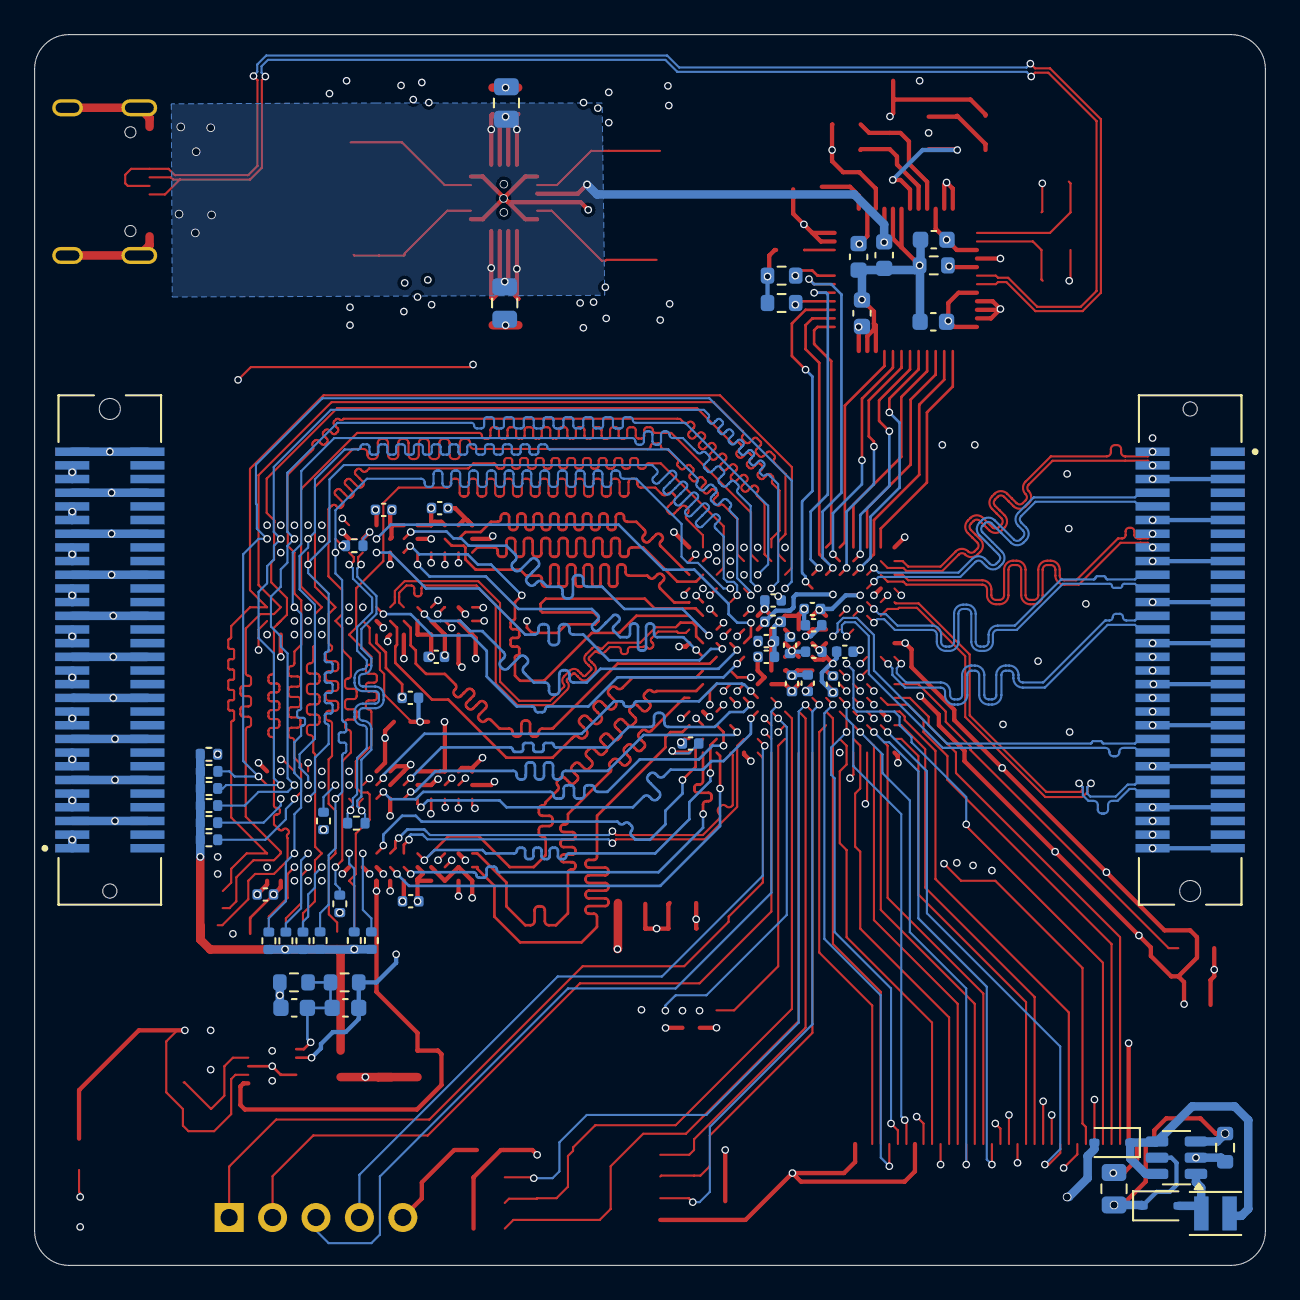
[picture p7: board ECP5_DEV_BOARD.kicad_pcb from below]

Board: 6 copper layers, 72.0 x 72.0 mm, 144 parts (57 on the bottom side), 189 nets.
